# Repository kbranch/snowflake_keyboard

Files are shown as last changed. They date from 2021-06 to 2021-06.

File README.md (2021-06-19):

# Snowflake Keyboard
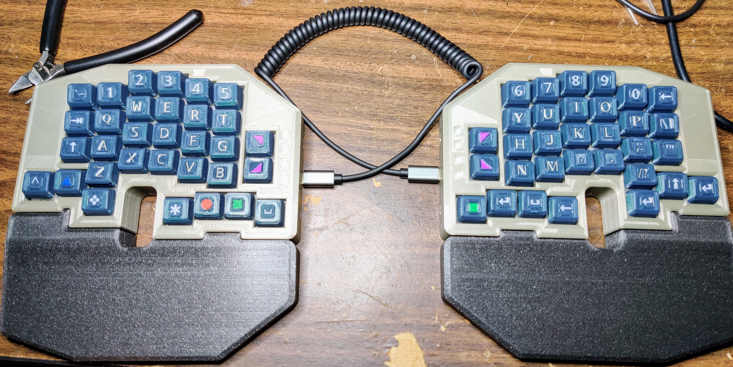
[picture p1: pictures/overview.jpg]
Overview Image


This is a weird, tightly spaced split keyboard that I designed to be very specific to my needs. It uses 17x16 mm key spacing rather than the standard 19x19 mm (inspired by [this post](https://www.reddit.com/r/ErgoMechKeyboards/comments/hudjyt/current_research_on_ergonomics_keyboard_design/)). The odd keys on the outside bottom corners are meant to be pressed with the pinky's knuckle rather than a fingertip. I haven't included every detail necessary to build the whole keyboard since it's so specific to my needs, but I'm happy to share and/or answer questions if somebody is interested in more detail for some reason.

The original CAD files are public on OnShape: [Case](https://cad.onshape.com/documents/9b32c1e8e8106ea44925f1b6/w/90cc6aeac4d327d0808a83e7/e/3e782787b37f9a3620b3203b) and [Keycaps](https://cad.onshape.com/documents/7a9b7e869b26a13f2521e861/w/94ad519ba1de32380f27d44b/e/4a5e31582eda700c8368bdb9). Generating the keycap legends is a pretty manual and sometimes fiddly process. I believe I included copies of all of the STLs I used, but I may have forgotten a few. 3mf files are included for the keycaps and legends, which should load into PrusaSlicer with all models in their correct quantities and print settings ready to go for a Prusa i3 MK3S.

All 3D printed parts are designed to be printed without support. I used manual mid-print color changes to embed the LED diffuser pieces into the case and for the keycap legends. M2 screws and nuts hold the PCB and plate to the case, and M3 screws and nuts hold the case halves and palm rests together. Little o-rings sit between the plate and case.

I used USB-C for both the actual USB connector and the board to board connection. I repurposed some [USB-A to USB-C adapters](https://www.amazon.com/gp/product/B07VCZV3R4/ref=ppx_yo_dt_b_asin_title_o09_s00?ie=UTF8&psc=1) to use as panel mount USB-C connectors. I ended up needing to grind the fronts down a bit to allow for cables to snap in fully through the case thickness.

The referenced QMK version includes a small tweak to allow the brightness of the indicator LEDs to follow the regular LED animation brightness. The LEDs are set up to indicate the active layer and the status of num, caps and scroll lock - they're not intended for flashy animations.

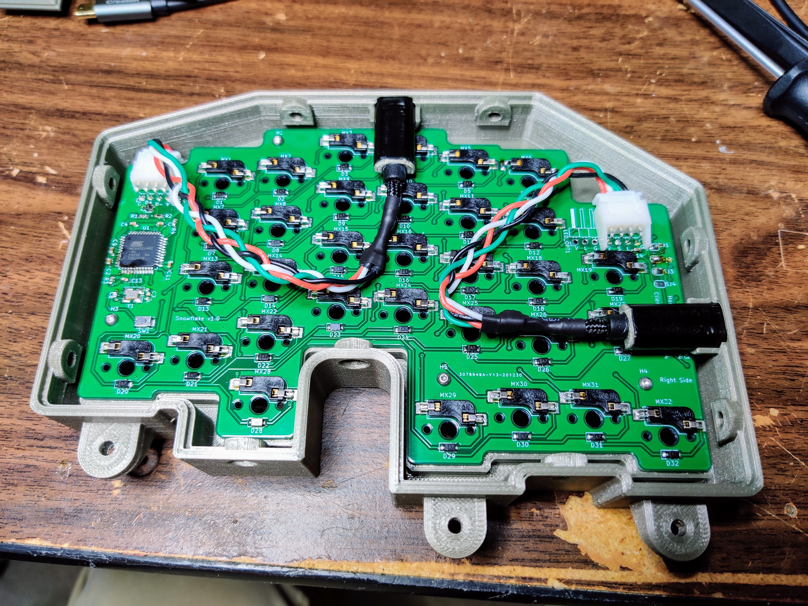
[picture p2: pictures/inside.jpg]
Inside Image


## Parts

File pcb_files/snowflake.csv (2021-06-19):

Id | Designator | Package | Quantity | Designation | Supplier and ref
1 | ,,,,,,, |  | 8
2 | SJ4,SJ3,SJ2,SJ1 | SolderJumper-2_P1.3mm_Open_RoundedPad1.0x1.5mm | 4 | SolderJumper
3 | C14,C1 | C_0603_1608Metric_Pad1.08x0.95mm_HandSolder | 2 | 10uf
4 | SW1 | SW_Push_SPST_NO_Alps_SKRK | 1 | SW_Push
5 | U3,U2 | TPD2E2U06DCKR | 2
6 | H5,H4,H3,H2,H1 | MountingHole_2.2mm_M2 | 5 | MountingHole
7 | Y1 | Crystal_SMD_3225-4Pin_3.2x2.5mm_HandSoldering | 1 | 16MHz
8 | U1 | TQFP-44_10x10mm_P0.8mm | 1 | ATmega32U4RC-AU
9 | R5 | R_0603_1608Metric_Pad0.98x0.95mm_HandSolder | 1 | 470
10 | R4,R3 | R_0603_1608Metric_Pad0.98x0.95mm_HandSolder | 2 | 10k
11 | R2,R1 | R_0603_1608Metric_Pad0.98x0.95mm_HandSolder | 2 | 22
12 | MX32,MX31,MX30,MX29,MX28,MX27,MX26,MX25,MX24,MX23,MX22,MX21,MX20,MX19,MX18,MX17,MX16,MX15,MX14,MX13,MX12,MX11,MX10,MX9,MX8,MX7,MX6,MX5,MX4,MX3,MX2,MX1 | Kailh_socket_MX | 32 | MX-NoLED
13 | SPLIT1 | PinHeader_1x04_P2.54mm_Horizontal | 1 | SPLIT
14 | LED_OPT1 | PinHeader_1x03_P2.54mm_Horizontal | 1 | LED
15 | USB1 | PinHeader_1x04_P2.54mm_Horizontal | 1 | USB
16 | F1 | Fuse_0805_2012Metric_Castellated | 1 | 500ma
17 | D36,D35,D34,D33 | LED_SK6805_PLCC4_2.4x2.7mm_P1.3mm | 4 | SK6805
18 | D32,D27,D19,D31,D26,D18,D12,D6,D30,D25,D17,D11,D5,D29,D24,D16,D10,D4,D23,D15,D9,D3,D28,D22,D14,D8,D2,D21,D13,D7,D1,D20 | D_SOD-123 | 32 | D
19 | C13,C12,C11,C10,C6,C5,C4,C3,C2 | C_0603_1608Metric_Pad1.08x0.95mm_HandSolder | 9 | 0.1uf
20 | C9 | C_0603_1608Metric_Pad1.08x0.95mm_HandSolder | 1 | 1uf
21 | C8,C7 | C_0603_1608Metric_Pad1.08x0.95mm_HandSolder | 2 | 22pf

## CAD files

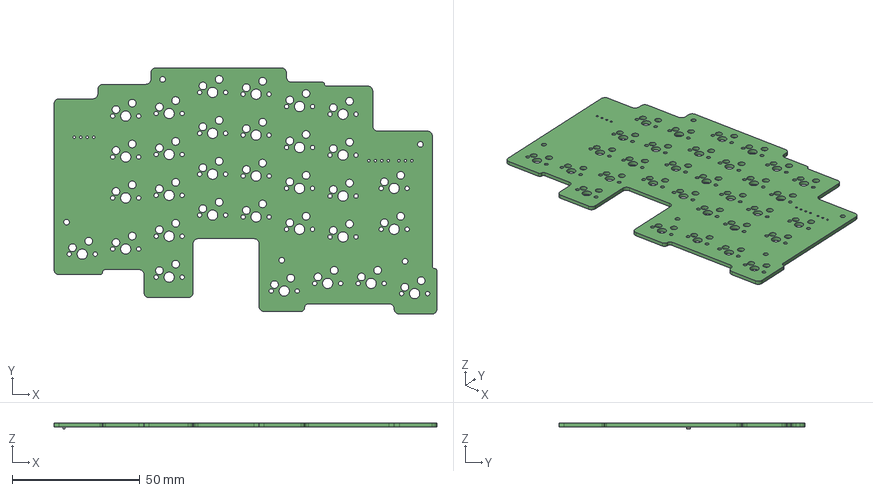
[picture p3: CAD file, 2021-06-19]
pcb_files/snowflake.step
149.8 x 96.3 x 2.45 mm

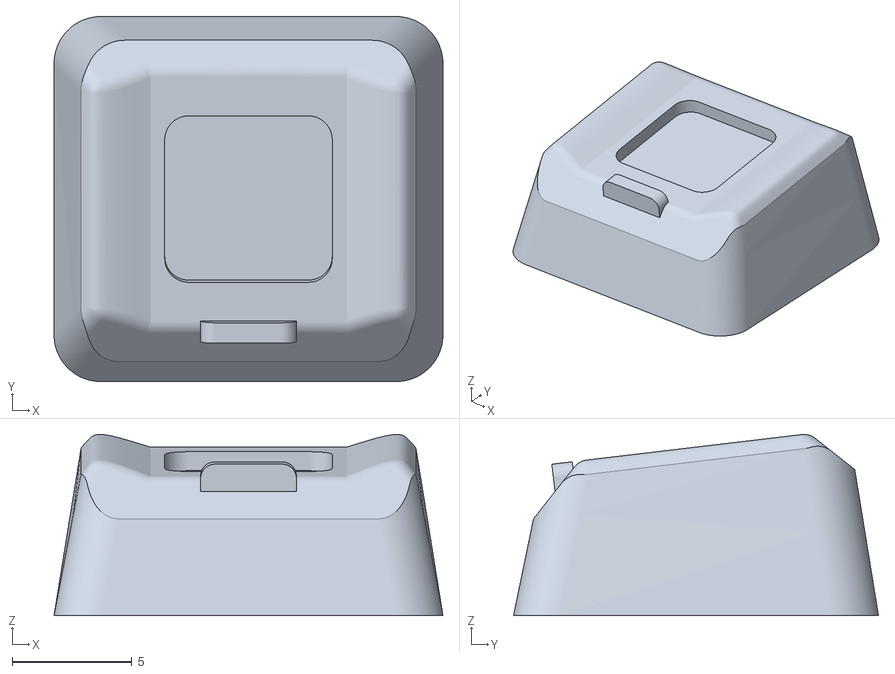
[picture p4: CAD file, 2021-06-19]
stls/keycaps/Keycap - R2 1U Compact Dished Bump.stl
16.2 x 15.2 x 7.57

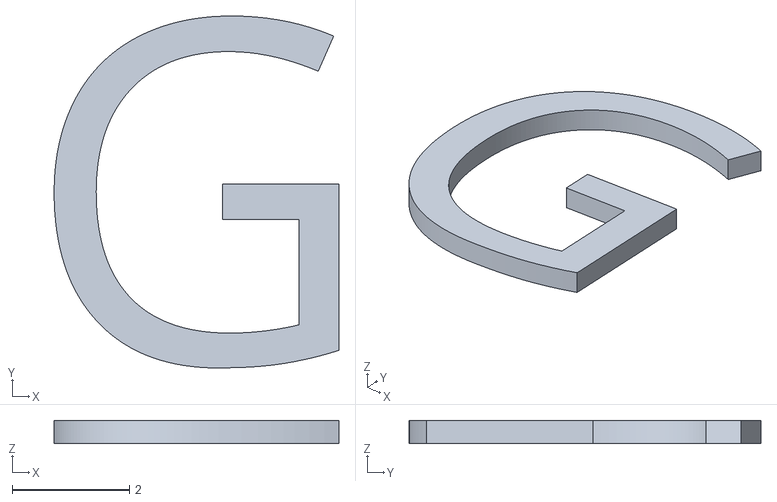
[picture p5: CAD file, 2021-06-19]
stls/keycaps/legends/Keycap - Legend - G.stl
4.87 x 6.01 x 0.4

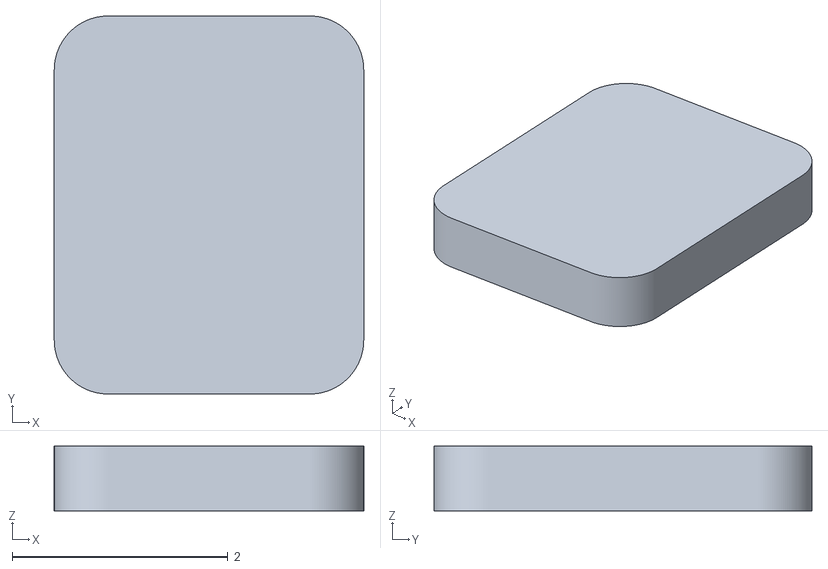
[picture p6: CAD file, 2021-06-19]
stls/Snowflake - Left LED Diffuser 3.stl
2.87 x 3.51 x 0.6

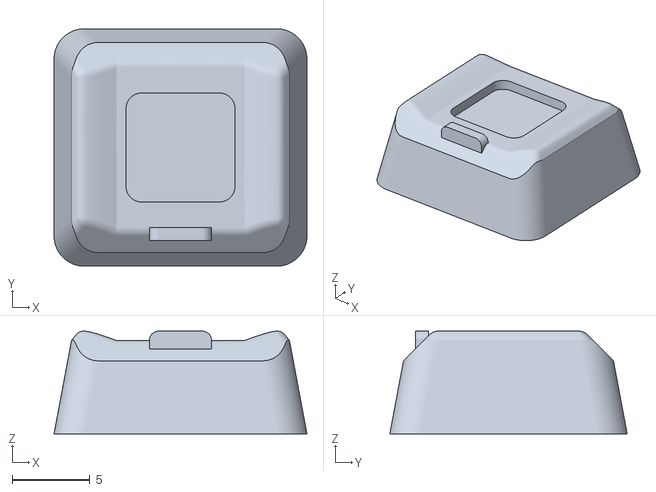
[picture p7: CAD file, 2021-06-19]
stls/keycaps/Keycap - R3 1U Compact Dished Bump.stl
16.2 x 15.2 x 6.60

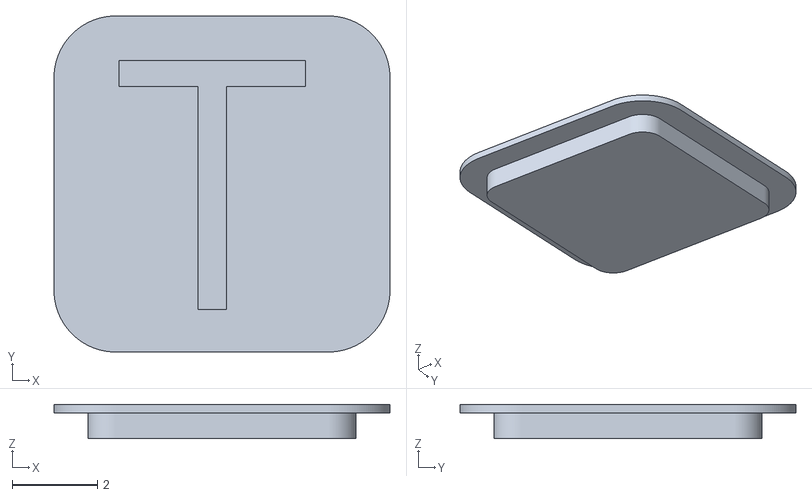
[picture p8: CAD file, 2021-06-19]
stls/keycaps/legends/Keycap - Legend Block - T.stl
7.90 x 7.90 x 0.8

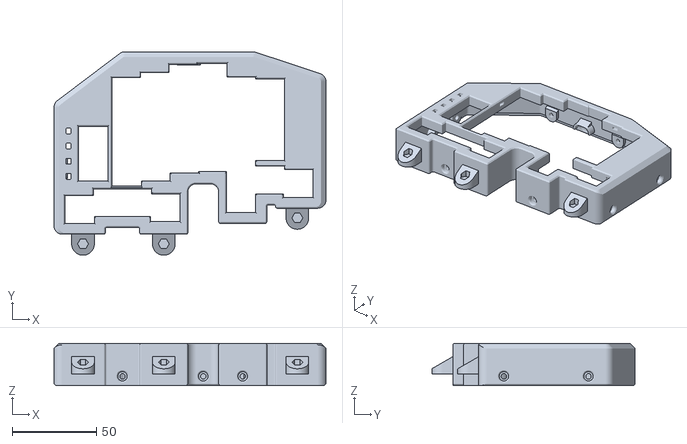
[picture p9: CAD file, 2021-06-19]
stls/Snowflake - Right Case.stl
161.8 x 121.0 x 25.1

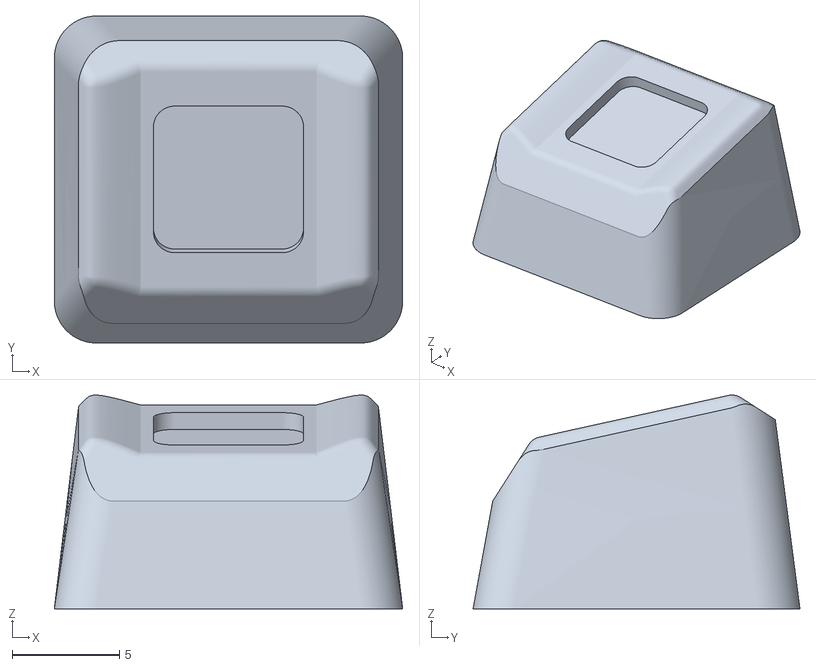
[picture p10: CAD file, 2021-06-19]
stls/keycaps/Keycap - R1 1U Compact Dished.stl
16.2 x 15.2 x 9.98

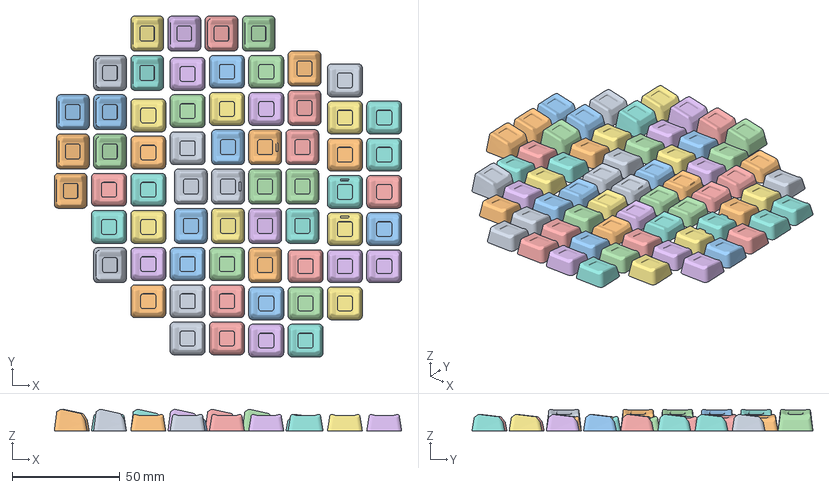
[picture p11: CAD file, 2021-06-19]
stls/keycaps/Snowflake Keycaps.3mf
161.2 x 158.2 x 9.98 mm
Keycap - R1 1U Compact Dished(6).stl
Keycap - R2 1U Compact Dished(2).stl
Keycap - R2 1U Compact Dished Bump(1).stl
Keycap - R3 1U Compact Dished Bump(1).stl
Keycap - R3 1U Compact Dished(2).stl
Keycap - R4 1U Compact Dished(2).stl

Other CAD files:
stls/keycaps/Keycap - R3 1U Compact Dished.stl
stls/keycaps/legends/Keycap - Legend Block - Return.stl
stls/Snowflake - Left Case.stl
stls/keycaps/legends/Keycap - Legend Block - 8.stl
stls/Snowflake - Right LED Diffuser 4.stl
stls/keycaps/Keycap - R4 1U Compact Dished.stl
stls/keycaps/legends/Keycap - Legend Block - Win.stl
stls/Snowflake - Right LED Diffuser 2.stl
stls/keycaps/legends/Keycap - Legend Block - C.stl
stls/Snowflake - Left LED Diffuser 2.stl
stls/Snowflake - Left LED Diffuser 4.stl
stls/Snowflake - Left Base.stl
stls/Snowflake - Left LED Diffuser 1.stl
stls/Snowflake - Left Palm Rest.stl
stls/Snowflake - Left Plate.stl
stls/Snowflake - Right Base.stl
stls/Snowflake - Right LED Diffuser 1.stl
stls/Snowflake - Right LED Diffuser 3.stl
stls/Snowflake - Right Palm Rest.stl
stls/Snowflake - Right Plate.stl
stls/keycaps/Keycap - R2 1U Compact Dished.stl
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

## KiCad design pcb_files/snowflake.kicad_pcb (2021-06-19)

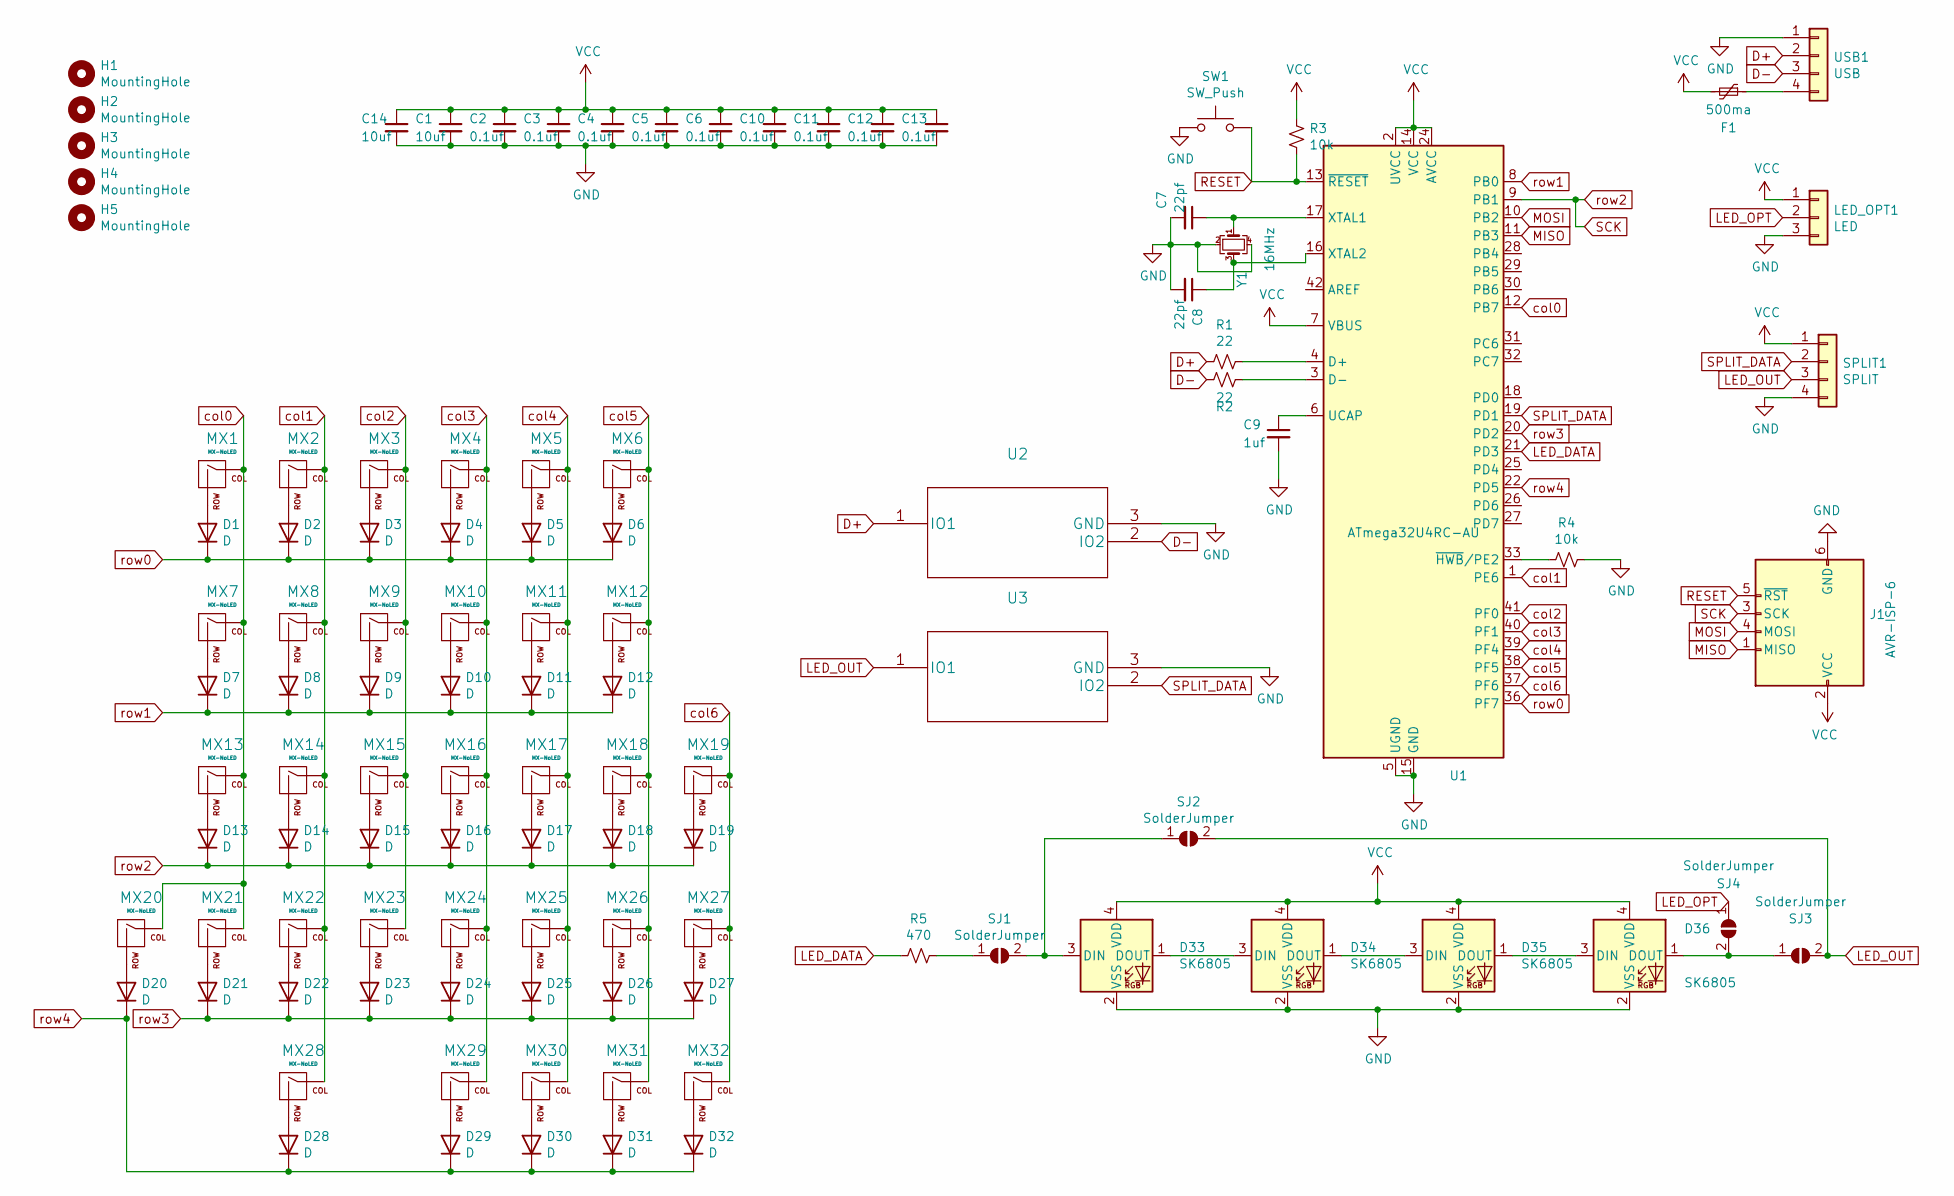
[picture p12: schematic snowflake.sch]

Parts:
C1, C14: 10uf; C_0603_1608Metric_Pad1.08x0.95mm_HandSolder
C2, C3, C4, C5, C6, C10, C11, C12, C13: 0.1uf; C_0603_1608Metric_Pad1.08x0.95mm_HandSolder
C7, C8: 22pf; C_0603_1608Metric_Pad1.08x0.95mm_HandSolder
C9: 1uf; C_0603_1608Metric_Pad1.08x0.95mm_HandSolder
D1, D2, D3, D4, D5, D6, D7, D8, D9, D10, D11, D12, D13, D14, D15, D16, D17, D18, D19, D20, D21, D22, D23, D24, D25, D26, D27, D28, D29, D30, D31, D32: D; D_SOD-123
D33, D34, D35, D36: SK6805; LED_SK6805_PLCC4_2.4x2.7mm_P1.3mm
F1: 500ma; Fuse_0805_2012Metric_Castellated
H1, H2, H3, H4, H5: MountingHole; MountingHole_2.2mm_M2
J1: AVR-ISP-6; PinHeader_2x03_P2.54mm_Vertical
LED_OPT1: LED; PinHeader_1x03_P2.54mm_Horizontal
MX1, MX2, MX3, MX4, MX5, MX6, MX7, MX8, MX9, MX10, MX11, MX12, MX13, MX14, MX15, MX16, MX17, MX18, MX19, MX20, MX21, MX22, MX23, MX24, MX25, MX26, MX27, MX28, MX29, MX30, MX31, MX32: MX-NoLED; Kailh_socket_MX
R1, R2: 22; R_0603_1608Metric_Pad0.98x0.95mm_HandSolder
R3, R4: 10k; R_0603_1608Metric_Pad0.98x0.95mm_HandSolder
R5: 470; R_0603_1608Metric_Pad0.98x0.95mm_HandSolder
SJ1, SJ2, SJ3, SJ4: SolderJumper; SolderJumper-2_P1.3mm_Open_RoundedPad1.0x1.5mm
SPLIT1: SPLIT; PinHeader_1x04_P2.54mm_Horizontal
SW1: SW_Push; SW_Push_SPST_NO_Alps_SKRK
U1: ATmega32U4RC-AU; TQFP-44_10x10mm_P0.8mm
U2, U3: TPD2E2U06DCKR
USB1: USB; PinHeader_1x04_P2.54mm_Horizontal
Y1: 16MHz; Crystal_SMD_3225-4Pin_3.2x2.5mm_HandSoldering

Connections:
D+: R1.2, U2.1 (IO1), USB1.2
D-: R2.2, U2.2 (IO2), USB1.3
GND: C1.2, C2.2, C3.2, C4.2, C5.2, C6.2, C7.2, C8.2, C9.2, C10.2, C11.2, C12.2, C13.2, C14.2, D33.2 (VSS), D34.2 (VSS), D35.2 (VSS), D36.2 (VSS), J1.6 (GND), LED_OPT1.3, R4.1, SPLIT1.4, SW1.1, U1.5 (UGND), U1.15 (GND), U1.23 (GND), U1.35 (GND), U1.43 (GND), U2.3 (GND), U3.3 (GND), USB1.1, Y1.2, Y1.4; also elsewhere on the board
LED_DATA: R5.2, U1.21 (PD3)
LED_OPT: LED_OPT1.2, SJ4.1 (A)
LED_OUT: SJ2.2 (B), SJ3.2 (B), SPLIT1.3, U3.1 (IO1)
MISO: J1.1 (MISO), U1.11 (PB3); also elsewhere on the board
MOSI: J1.4 (MOSI), U1.10 (PB2); also elsewhere on the board
unnamed: C7.1, U1.17 (XTAL1), Y1.1
unnamed: C8.1, U1.16 (XTAL2), Y1.3
unnamed: C9.1, U1.6 (UCAP)
unnamed: D1.2 (A), MX1.2 (ROW)
unnamed: D2.2 (A), MX2.2 (ROW)
unnamed: D3.2 (A), MX3.2 (ROW)
unnamed: D4.2 (A), MX4.2 (ROW)
unnamed: D5.2 (A), MX5.2 (ROW)
unnamed: D6.2 (A), MX6.2 (ROW)
unnamed: D7.2 (A), MX7.2 (ROW)
unnamed: D8.2 (A), MX8.2 (ROW)
unnamed: D9.2 (A), MX9.2 (ROW)
unnamed: D10.2 (A), MX10.2 (ROW)
unnamed: D11.2 (A), MX11.2 (ROW)
unnamed: D12.2 (A), MX12.2 (ROW)
unnamed: D13.2 (A), MX13.2 (ROW)
unnamed: D14.2 (A), MX14.2 (ROW)
unnamed: D15.2 (A), MX15.2 (ROW)
unnamed: D16.2 (A), MX16.2 (ROW)
unnamed: D17.2 (A), MX17.2 (ROW)
unnamed: D18.2 (A), MX18.2 (ROW)
unnamed: D19.2 (A), MX19.2 (ROW)
unnamed: D20.2 (A), MX20.2 (ROW)
unnamed: D21.2 (A), MX21.2 (ROW)
unnamed: D22.2 (A), MX22.2 (ROW)
unnamed: D23.2 (A), MX23.2 (ROW)
unnamed: D24.2 (A), MX24.2 (ROW)
unnamed: D25.2 (A), MX25.2 (ROW)
unnamed: D26.2 (A), MX26.2 (ROW)
unnamed: D27.2 (A), MX27.2 (ROW)
unnamed: D28.2 (A), MX28.2 (ROW)
unnamed: D29.2 (A), MX29.2 (ROW)
unnamed: D30.2 (A), MX30.2 (ROW)
unnamed: D31.2 (A), MX31.2 (ROW)
unnamed: D32.2 (A), MX32.2 (ROW)
unnamed: D33.1 (DOUT), D34.3 (DIN)
unnamed: D33.3 (DIN), SJ1.2 (B), SJ2.1 (A)
unnamed: D34.1 (DOUT), D35.3 (DIN)
unnamed: D35.1 (DOUT), D36.3 (DIN)
unnamed: D36.1 (DOUT), SJ3.1 (A), SJ4.2 (B)
unnamed: F1.1, USB1.4
unnamed: R1.1, U1.4 (D+)
unnamed: R2.1, U1.3 (D-)
unnamed: R4.2, U1.33 (~HWB~/PE2)
unnamed: R5.1, SJ1.1 (A)
RESET: J1.5 (~RST), R3.1, SW1.2, U1.13 (~RESET); also elsewhere on the board
SCK: D13.1 (K), D14.1 (K), D15.1 (K), D16.1 (K), D17.1 (K), D18.1 (K), D19.1 (K), J1.3 (SCK), U1.9 (PB1); also elsewhere on the board
SPLIT_DATA: SPLIT1.2, U1.19 (PD1), U3.2 (IO2)
VCC: C1.1, C2.1, C3.1, C4.1, C5.1, C6.1, C10.1, C11.1, C12.1, C13.1, C14.1, D33.4 (VDD), D34.4 (VDD), D35.4 (VDD), D36.4 (VDD), F1.2, J1.2 (VCC), LED_OPT1.1, R3.2, SPLIT1.1, U1.2 (UVCC), U1.7 (VBUS), U1.14 (VCC), U1.24 (AVCC), U1.34 (VCC), U1.44 (AVCC); also elsewhere on the board
col0: MX1.1 (COL), MX7.1 (COL), MX13.1 (COL), MX20.1 (COL), MX21.1 (COL), U1.12 (PB7)
col1: MX2.1 (COL), MX8.1 (COL), MX14.1 (COL), MX22.1 (COL), MX28.1 (COL), U1.1 (PE6)
col2: MX3.1 (COL), MX9.1 (COL), MX15.1 (COL), MX23.1 (COL), U1.41 (PF0)
col3: MX4.1 (COL), MX10.1 (COL), MX16.1 (COL), MX24.1 (COL), MX29.1 (COL), U1.40 (PF1)
col4: MX5.1 (COL), MX11.1 (COL), MX17.1 (COL), MX25.1 (COL), MX30.1 (COL), U1.39 (PF4)
col5: MX6.1 (COL), MX12.1 (COL), MX18.1 (COL), MX26.1 (COL), MX31.1 (COL), U1.38 (PF5)
col6: MX19.1 (COL), MX27.1 (COL), MX32.1 (COL), U1.37 (PF6)
row0: D1.1 (K), D2.1 (K), D3.1 (K), D4.1 (K), D5.1 (K), D6.1 (K), U1.36 (PF7)
row1: D7.1 (K), D8.1 (K), D9.1 (K), D10.1 (K), D11.1 (K), D12.1 (K), U1.8 (PB0)
row3: D21.1 (K), D22.1 (K), D23.1 (K), D24.1 (K), D25.1 (K), D26.1 (K), D27.1 (K), U1.20 (PD2)
row4: D20.1 (K), D28.1 (K), D29.1 (K), D30.1 (K), D31.1 (K), D32.1 (K), U1.22 (PD5)

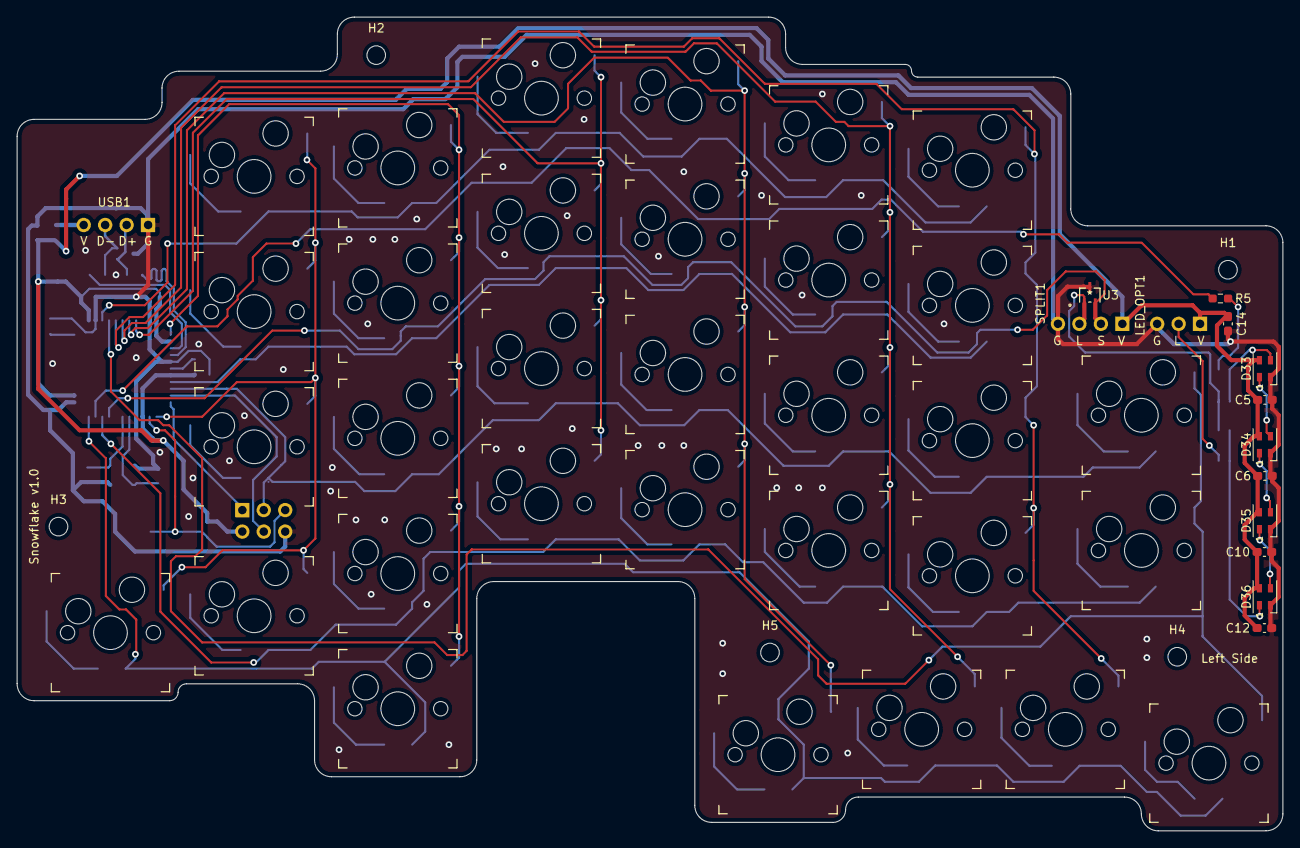
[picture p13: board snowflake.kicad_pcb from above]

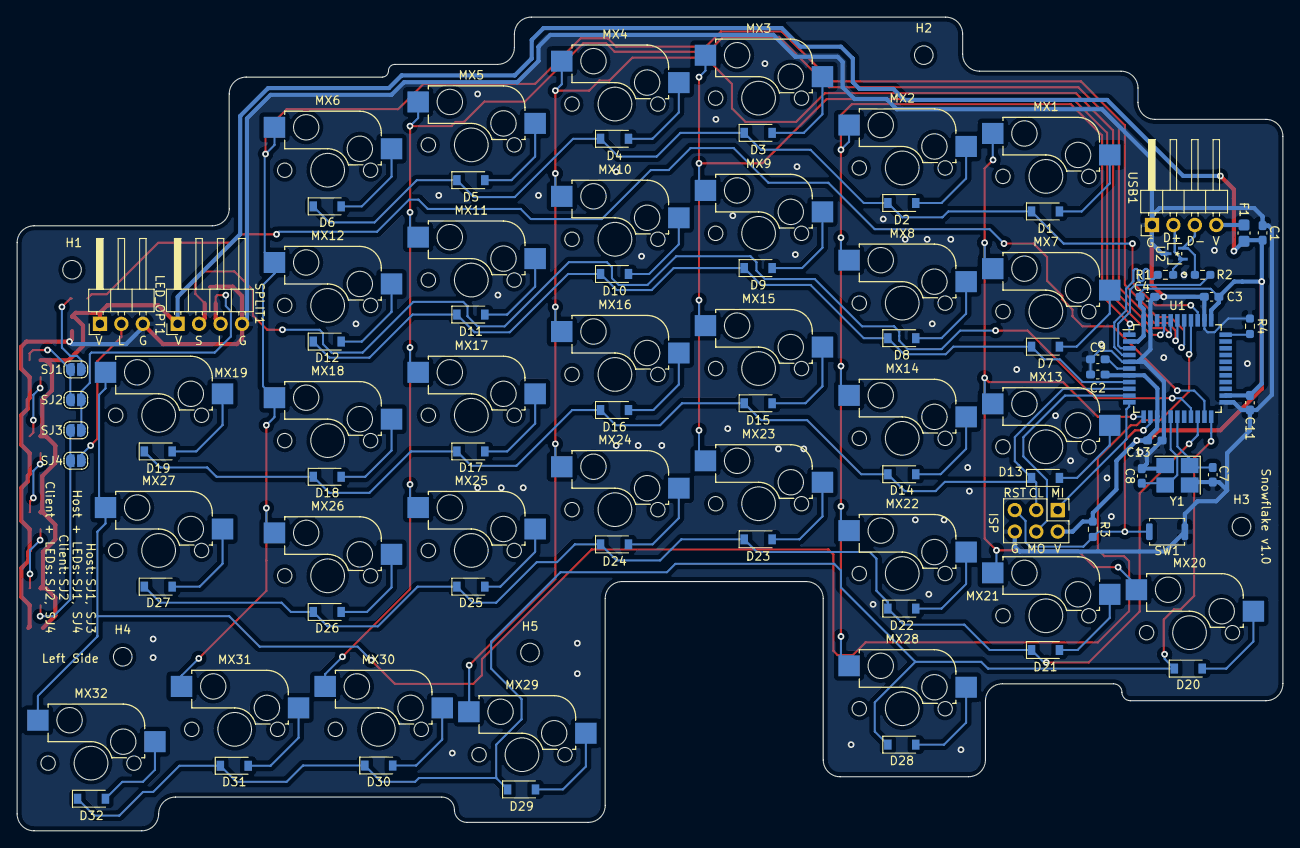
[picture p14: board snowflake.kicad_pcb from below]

Board: 2 copper layers, 149.8 x 96.3 mm, 106 parts (58 on the bottom side), 68 nets.

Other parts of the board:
ISP: AVR-ISP-6; PinHeader_2x03_P2.54mm_Vertical

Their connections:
GND: ISP.6; also elsewhere on the board
MISO: ISP.1; also elsewhere on the board
MOSI: ISP.4; also elsewhere on the board
RESET: ISP.5; also elsewhere on the board
SCK: ISP.3; also elsewhere on the board
VCC: ISP.2; also elsewhere on the board

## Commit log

2021-06-19 Added a couple pictures
2021-06-19 Renamed the 3mf files
    [Snoflake Alphas.3mf, Snowflake Keycaps.3mf, Snowflake layers.3mf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]

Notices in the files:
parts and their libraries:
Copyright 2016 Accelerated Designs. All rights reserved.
